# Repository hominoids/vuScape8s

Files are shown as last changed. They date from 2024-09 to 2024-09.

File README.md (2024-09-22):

## vuScape8s

Integrated Odorid-Vu8s Case with either Odorid-M2 or Odorid-M1s and UPS.

### Introduction

The vuScape8s is the next generation in the vuScape series and incorporates several new features for Hardkernel’s 15th anniversary and celebratory release of the Odroid-M1s and version 2 incorporated the Odroid-M2. Thanks to the Vu8S, this is the thinnest vuScape yet and can also integrate the optional M1s-UPS accessory in landscape or portrait orientation with the Odroid-M1s. 



### Features
- Odroid-M1S or Odroid-M2
- Supports all Landscape and Portrait Orientations e.g. standard, left, right, inverted
- Viewing Angle 10-23 Degrees
- Adjustable Bottom Clearance Bracket Height
- Corner Mount Hardware Selection (insert, nut, recessed, thru hole)
- Selectable SBC Cooling (fan, vent, top cover openings)
- Selectable GPIO Openings
- HK OEM Case Support
- UPS Integration, Side or Bottom (M1S Only)
- UPS External Power Button (M1S Only)
- UPS LED Accent Down Lighting (M1S Only)
- Customizer GUI

All case covers were designed so they can be removed without disturbing the mounted SBC or UPS. The orientation of the stand brackets can also be changed without any other disassembly and for the M1s, the power button on the back of the UPS can be used to power up the unit when it is off. The Odroid-M2 also has a power button on the case cover.

### BOM
-  LCD Shell and Brackets (4)M3x14mm and (4) M3x4mm inserts or M3 nuts
-  Back Frame (4) M3x6mm Countersink Screws
-  SBC mount (4) M3x4mm inserts and (4) M3x4mm Cap Screws
-  SBC Cover or OEM Case (4) M3x4mm inserts and (4) M3x4mm Cap Screws

### Build Notes
The landscape and portrait brackets need to be printed using solid fill, and most likely with a wide brim, but the back frame can use a partial fill.  Obviously inserts need only be installed in the locations being used on the frame.  Regarding the LCD panel encasement, it is important not to over tighten the mount screws because they will impose extraneous light on the front of the LCD from the pressure.  If you see light around the edges loosen the nearest screw(s) until it disappears.  I tighten them until they seat and then loose them until there is no play in the assembly, what I would describe as taut, it just holds it closed but doesn’t apply pressure.

The SBC cover spacing is the same as the HK OEM Case which can be used instead of the direct mounted SBC and cover.

License: GPLv3.

### Notes

  More information can be found at this [Hard Kernel forum thread](https://forum.odroid.com/viewtopic.php?f=217&t=47691)

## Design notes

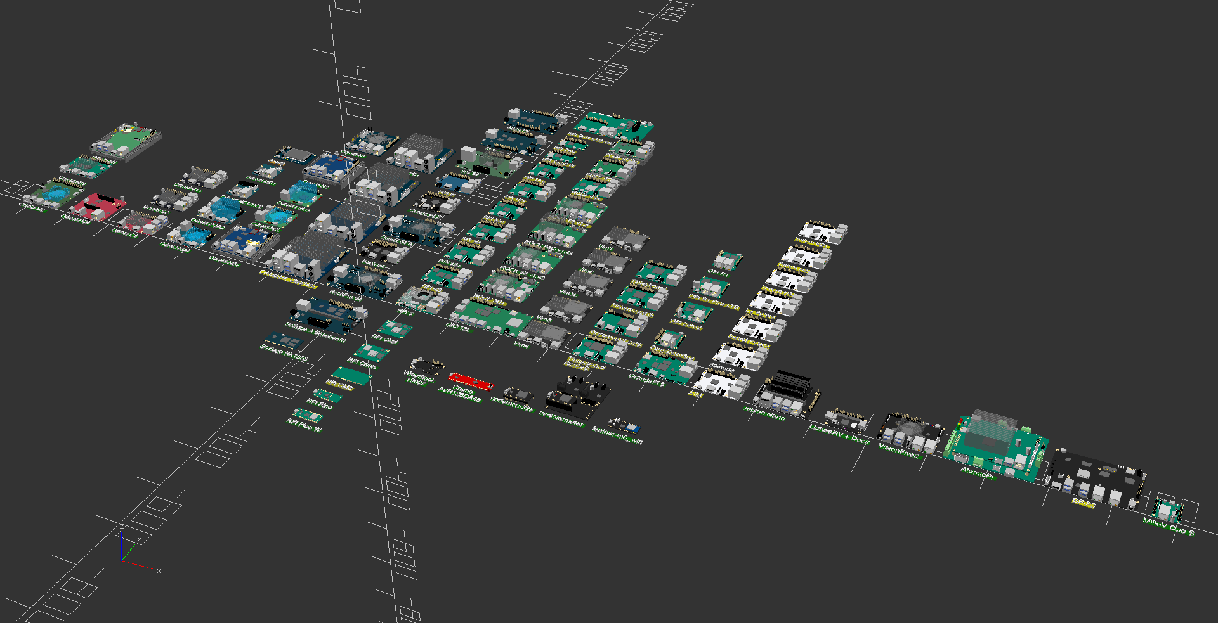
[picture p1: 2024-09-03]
SBC_Model_Framework/sbc_models.png

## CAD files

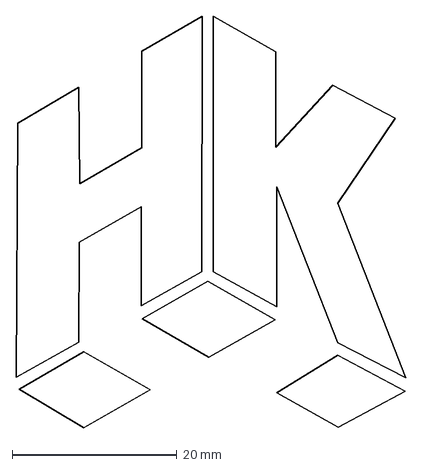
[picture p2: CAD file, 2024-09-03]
SBC_Model_Framework/dxf/hk_50mm.dxf
47.3 x 50.0 mm

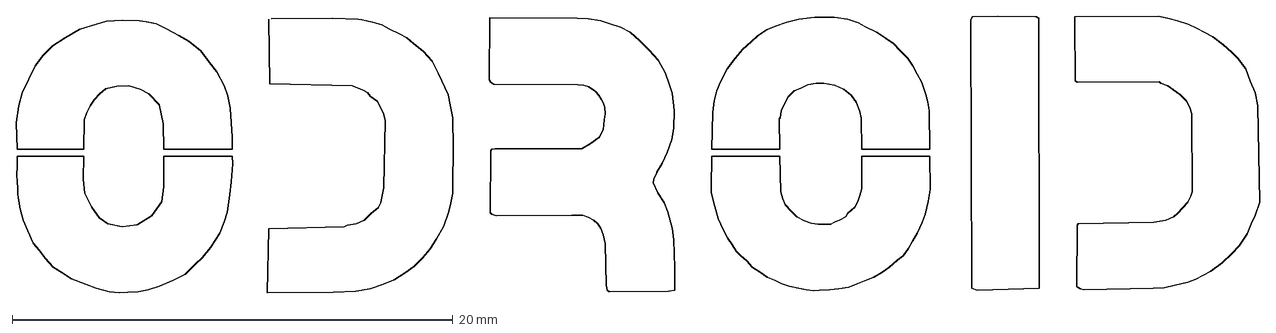
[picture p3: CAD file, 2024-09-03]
SBC_Model_Framework/dxf/odroid.dxf
56.4 x 12.6 mm

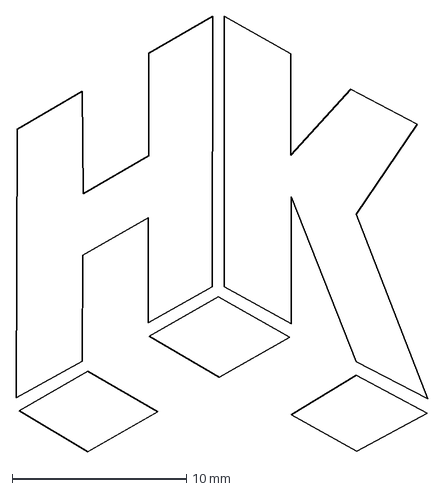
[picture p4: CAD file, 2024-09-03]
SBC_Model_Framework/dxf/hk_25mm.dxf
23.7 x 25.0 mm

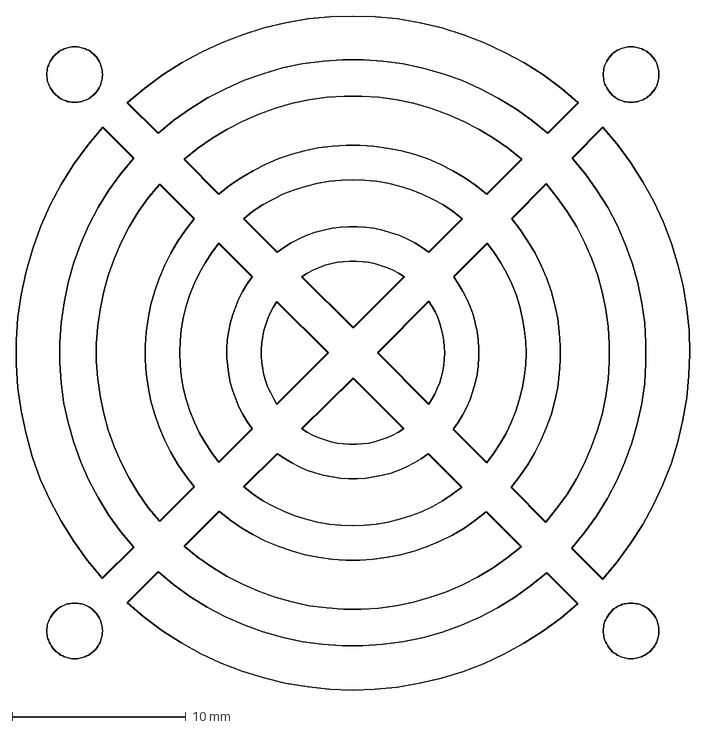
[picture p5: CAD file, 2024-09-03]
SBC_Model_Framework/dxf/customfan.dxf
38.7 x 38.8 mm

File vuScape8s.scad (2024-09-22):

/*
    vuScape8s Case Copyright 2023 Edward A. Kisiel
    hominoid @ www.forum.odroid.com

    This program is free software: you can redistribute it and/or modify
    it under the terms of the GNU General Public License as published by
    the Free Software Foundation, either version 3 of the License, or
    (at your option) any later version.

    but WITHOUT ANY WARRANTY; without even the implied warranty of
    MERCHANTABILITY or FITNESS FOR A PARTICULAR PURPOSE.  See the
    GNU General Public License for more details.

    You should have received a copy of the GNU General Public License
    along with this program.  If not, see <http://www.gnu.org/licenses/>.
    Code released under GPLv3: http://www.gnu.org/licenses/gpl.html

    20231204 Version 1.0    vuScape8s, Odroid-M1s and M1s-UPS integrated case initial release.
    20240921 Version 2.0    Added Odroid-M2, upgraded to released SBC Model Framework,
                            for both M2 and M1s variations added more cooling options, 
                            increased venting for NVME, support for all landscape
                            and portrait orientations.
    
    vuscape8s_assembled()
    case_front()
    case_back()
    back_frame()
    sbc_cover()
    ups_cover()
    bracket(side)

*/

use <./lib/fillets.scad>;
use <./lib/vuScape8s_library.scad>;
use <./SBC_Model_Framework/sbc_models.scad>;

/* [View] */
view = "model";  // [model, platter, part]
individual_part = "back"; // [front, back, frame, sbc_cover, ups_cover, ups_button, bracket_left, bracket_right]
vu8s_on = true;
move_front = 0; // [-1:200]
move_back = 0; // [-1:200]
sbc_on = true;
move_sbc_cover = 0; // [-1:200]
ups_on = false;
move_ups_cover = 0; // [-1:200]

/* [Adjustments] */
sbc_model = "m2"; // ["m1s","m2"]
orientation = "landscape"; // [landscape, portrait]
flip_view = true;
view_angle = 15; // [10:1:23]
view_height = 24; // [10:.5:40]
view_size = [172.5,107.5,.125]; // [1:.125:175]
vu8s_mount = "insert"; // [thruhole, recessed, nut, insert]
sbc_mount = "insert"; // [none, insert, recessed]
right_pillar_mount = "recessed"; // [none, thruhole, recessed]
insert_dia = 4.2; // [2:.1:5] 

/* [Options] */
brackets = true;
backframe = true;
gpio_opening = "default"; // [default,none,open,block,knockout,vent]

top_cover_pattern = "hex_5mm"; //[solid,hex_5mm,hex_8mm,linear_vertical,linear_horizontal]
cooling = "none"; // [default,none,open,fan_open,fan_1,fan_2,fan_hex,vent,vent_hex_5mm,vent_hex_8mm,custom]
fan_size = 0; // [0,25,30,40,50,60,70,80,92]

ups_led_down_light =  false;
ups_location = "none"; // [none, bottom, side]
prototype_m1s_on = false;
prototype_ups_on = false;

/* [Hidden] */
wallthick = 2;
floorthick = 1.5;
frontthick = 1.5;
gap = 1;
sbc_cover_gap = 2;
sbc_size = sbc_model == "m2" ? [90,90,17] : [90,65,15];

c_fillet = 4;
fillet = 0;
lcd_size = [202,153,4.45];
//view_size = [172.5,107.5,.125];
pcb_tmaxz = 5.5;
pcb_bmaxz = 0;

width = lcd_size[0]+(2*(wallthick+gap));
depth = lcd_size[1]+(2*(wallthick+gap));
front_height = pcb_tmaxz+frontthick;
back_height = pcb_bmaxz+floorthick;
case_z = back_height+front_height;

top_standoff=[      7.5,   // radius
                    2.5,   // height
                    2.7,   // holesize
                   10,     // supportsize
                    2.5,   // supportheight
                    1,     // 0=none, 1=countersink, 2=recessed hole, 3=nut holder, 4=blind hole
                    1,     // standoff style 0=hex, 1=cylinder
                    0,     // enable reverse standoff
                    0,     // enable insert at top of standoff
                    4.5,   // insert hole dia. mm
                    5.1];  // insert depth mm
                  
bottom_standoff=[ 5.2,     // radius
                    floorthick+1, // height
                    2.7,   // holesize
                   6.2,     // supportsize
                    floorthick+1, // supportheight
                    0,     // 0=none, 1=countersink, 2=recessed hole, 3=nut holder, 4=blind hole
                    0,     // standoff style 0=hex, 1=cylinder
                    0,     // enable reverse standoff
                    0,     // enable insert at top of standoff
                    4.5,   // insert hole dia. mm
                    5.1];  // insert depth mm
                  
adj = .1;
$fn = 90;
cover_offset = sbc_model == "m2" ? 25 : 0;

// model view
if (view == "model" && orientation == "landscape" && flip_view == false) {
    // landscape
    translate([(width/2),-40,view_height-2+(view_angle-15)]) rotate([90+view_angle,0,180]) 
        vuscape8s_assembled();
}
if (view == "model" && orientation == "landscape" && flip_view == true) {
    // landscape
    translate([-(width/2),0,view_height-8+depth+(view_angle-15)]) rotate([90-view_angle,180,180]) 
        vuscape8s_assembled();
}
if (view == "model" && orientation == "portrait") {
    translate([-(depth/2),-40,view_height-2+(view_angle-15)]) rotate([0,270-view_angle,270]) {  // portrait
        if(move_front >= 0) {
            color("grey",1) translate([0,0,-move_front]) case_front();
        }
        if(move_back >= 0) {
            color("dimgrey",1) translate([0,0,front_height-(back_height/2)+move_back+adj]) case_back();
        }
        if(vu8s_on == true) {
            translate([gap+wallthick+lcd_size[0],gap+wallthick+10,2.5+frontthick]) rotate([0,180,0]) hk_vu8s();
        }
        if(sbc_on == true) {
            translate([162,115.5,5.5+front_height]) rotate([0,0,180]) sbc(sbc_model);
        }
        if((move_sbc_cover >= 0 && prototype_m1s_on == false) || (move_sbc_cover >= 0 && sbc_model == "m2")) {
            translate([gap+wallthick+66,gap+wallthick+44-cover_offset,front_height+4+move_sbc_cover]) 
                sbc_cover();
        }
        if(ups_on == true && sbc_model == "m1s") {
            if(ups_location == "bottom") {
                translate([16.5,137.25,4+front_height]) rotate([0,0,270]) hk_m1s_ups();
            }
            if(ups_location == "side") {
                translate([60,12.5,4+front_height]) hk_m1s_ups();
            }
        }
        if(move_ups_cover >= 0 && sbc_model == "m1s") {
            if(ups_location == "bottom") {
                translate([13.5,140,4+front_height+move_ups_cover]) rotate([0,0,270]) ups_cover();
            }
            if(ups_location == "side") {
                translate([57.25,9.5,4+front_height+move_ups_cover]) ups_cover();
            }
        }
        if(prototype_m1s_on == true && sbc_model == "m1s") {
            translate([72,50.5,18+front_height]) proto_m1s();
        }
        if(prototype_ups_on == true && sbc_model == "m1s") {
            if(ups_location == "side") {
                translate([60,12.5,4+front_height]) proto_ups();
            }
            if(ups_location == "bottom") {
                translate([16.5,137.25,4+front_height]) rotate([0,0,270]) proto_ups();
            }
        }
        if(backframe == true) {
         translate([0,0,front_height]) back_frame();
        }
        if(brackets == true && orientation == "landscape" && flip_view == false) {
         translate([gap+wallthick+8.5,4.5,front_height]) bracket("left");
         translate([width-.5,4.5,front_height]) bracket("right");
        }
        if(brackets == true && orientation == "landscape" && flip_view == true) {
         translate([gap+wallthick+width-14.5,depth-4.5,front_height]) rotate([0,0,180]) bracket("left");
         translate([.5,depth-4.5,front_height]) rotate([0,0,180]) bracket("right");
        }
        if(brackets == true && orientation == "portrait" && flip_view == false) {
         translate([gap+wallthick+1.5,depth-11.5,front_height]) rotate([0,0,270]) bracket("left");
         translate([2.5,.5,front_height]) rotate([0,0,270]) bracket("right");
        }
        if(brackets == true && orientation == "portrait" && flip_view == true) {
         translate([width+gap+wallthick-7.75,11.5,front_height]) rotate([0,0,90]) bracket("left");
         translate([width-2.5,depth-.5,front_height]) rotate([0,0,90]) bracket("right");
        }
    }
}
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

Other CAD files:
SBC_Model_Framework/sbc_library.scad
SBC_Model_Framework/sbc_models.scad
SBC_Model_Framework/sbc_models_library.scad
SBC_Model_Framework/sbc_models_viewer.scad

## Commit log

2024-03-27 added base files from initial release
    [sbc_library.scad, sbc_models.cfg, sbc_models.scad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]
2024-09-03 sbc_model_framework updated
    [customfan.dxf, fan_40.dxf, hk_25mm.dxf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]
2024-09-04 renamed library and removed unused modules and added odroid-m2 to gui.
    [vuScape8s.scad]
2024-09-05 initial work for m2 landscape orientation
    [vuScape8s.scad]
2024-09-05 changed uart mask to open and readme.md updates
    [vuScape8s.scad]
2024-09-08 added cooling, gpio and cover pattern selection in gui, added power button for m2, landscape and portrait implementation and other changes and fixes
    [sbc_models.cfg, vuScape8s.scad]
2024-09-09 fixed fan placment with pattern cover for m1s
    [vuScape8s.scad]
2024-09-13 m2 standoff trim for uart interference
    [vuScape8s.scad]
2024-09-15 updated sbc cover placement, changed masks for usb2, usb3 and hdmi, as well as other changes and updates
    [sbc_models.cfg, vuScape8s.scad]
2024-09-15 sbc cover openings placement adjustment
    [vuScape8s.scad]
2024-09-15 added landscape flip_view for 180 orientation
    [vuScape8s.scad]
2024-09-17 added model view for landscape flipped orientation, set as default, more mask adjustments
    [sbc_models.cfg, vuScape8s.scad]
2024-09-17 created better nvme ventilation per orientation and some code cleanup
    [vuScape8s.scad]
2024-09-18 more sbc cover opening alignment and adjustments
    [vuScape8s.scad]
2024-09-22 updated readme.md, vuscape8s.scad and made final adjustments for release
    [sbc_models.cfg, vuScape8s.scad]
2024-09-22 adjusted fan openings to correct height
    [vuScape8s.scad]
